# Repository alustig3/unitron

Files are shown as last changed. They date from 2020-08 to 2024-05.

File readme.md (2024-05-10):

# Unitron

<a href="https://certification.oshwa.org/us002571.html">

</a>

Unitron is a kitchen tool for working with important cooking units -- time, space, and mass -- using tactually-pleasing switches, knobs, and buttons, non-intrusive beeps, and exciting lights.

Unitron allows you to convert between common volume units (cups, ounces, tablespoons, teaspoons and milliliters). It can also convert from volume to mass (and vice-versa), taking into account the density of common cooking ingredients. This makes measuring ingredients for volume-based recipes with a kitchen scale a breeze. It also functions as a handy countdown timer!

Watch the demo video [here](https://vimeo.com/719658219).

Unitron was developed by Andy Lustig.

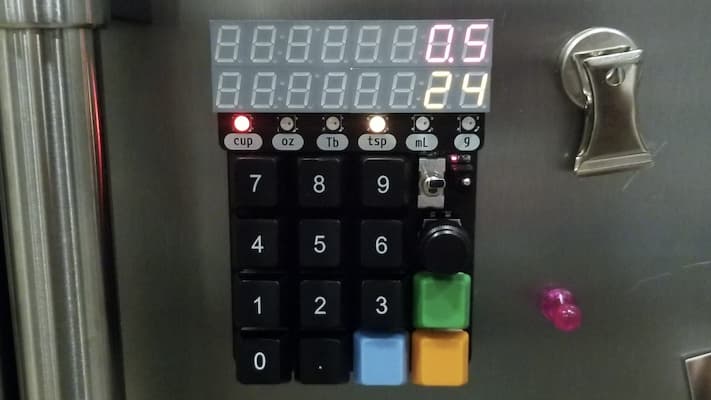
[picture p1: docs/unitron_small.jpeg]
unitron


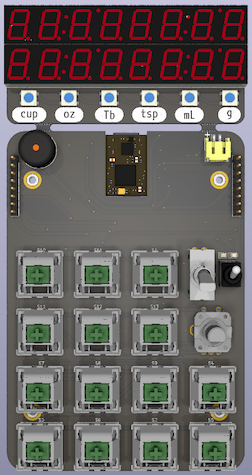
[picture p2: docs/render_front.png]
front render

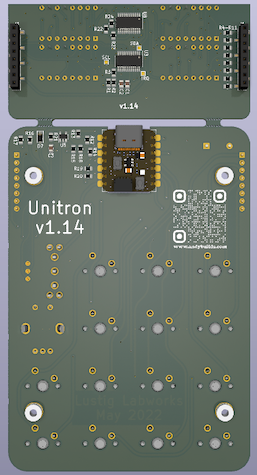
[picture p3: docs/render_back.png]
back render

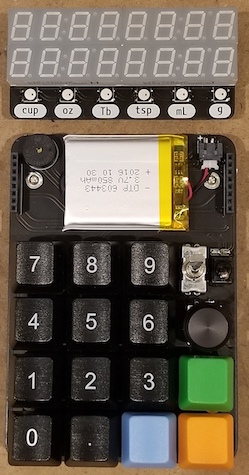
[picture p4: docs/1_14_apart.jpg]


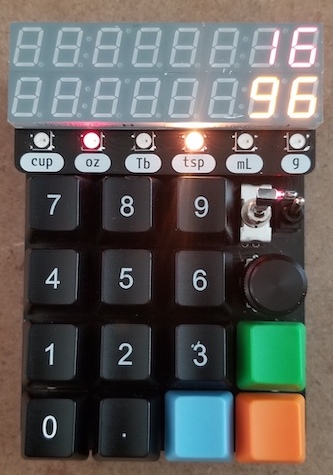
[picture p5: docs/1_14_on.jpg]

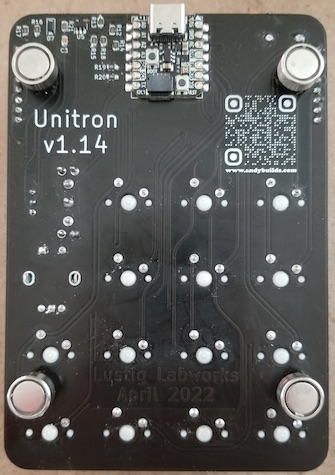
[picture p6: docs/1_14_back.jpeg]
back real


## Build Guide

### BOM

| Qty | Reference | Description | Value/MPN |
| --- | --- | --- | --- |
| 1 | BT2 | Battery Connector | [2468](https://www.digikey.com/product-detail/en/keystone-electronics/2466/36-2466-ND/303815) |
| 1 | C1 | 0805 Capacitor | 1µF |
| 1 | C2 | 0805 Capacitor | 100nF |
| 1 | C3 | 0805 Capacitor | 10µF |
| 6 | D1-6 | Addressable RGB LED | [WS2812B](https://cdn-shop.adafruit.com/datasheets/WS2812B.pdf) |
| 1 | D7 | Diode | [SM5817PL-TP](https://www.digikey.com/en/products/detail/micro-commercial-co/SM5817PL-TP/1793251) |
| 2 | D8, D9 | 0805 Indicator LED | Red and Yellow |
| 4 | H1-4 | Threaded Standoff | [4207](https://www.adafruit.com/product/4207) |
| 2 | J1, J3 | 1x8 male header | [TSM-108-01-T-SV](https://www.digikey.com/en/products/detail/samtec-inc/TSM-108-01-T-SV/6679033) |
| 2 | J2, J4 | 1x8 female header | [SSW-108-01-T-S](https://www.digikey.com/en/products/detail/samtec-inc/SSW-108-01-T-S/1112297) |
| 1 | LS1 | Buzzer | [PK-11N40PQ](https://www.digikey.com/en/products/detail/mallory-sonalert-products-inc/PK-11N40PQ/4996072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) |
| 21  | R1-18, R22-24 | 0805 Resistor | 10KΩ |
| 3 | R19, R20, R21 | 0805 Resistor | 2KΩ |
| 14  | S1-14 | Mechanical Key Switch | [Gateron green](https://www.amazon.com/Gateron-KS-9-Mechanical-Type-Switch/dp/B07X3TH4DS?th=1) |
| 1 | SW1 | Small Toggle | [B12AP](https://www.digikey.com/en/products/detail/nkk-switches/B12AP/379099) |
| 1 | SW2 | Big Toggle | [M2012EA2W13](https://www.digikey.com/en/products/detail/nkk-switches/M2012EA2W13/4509655) |
| 1 | SW3 | Rotary Encoder | [PEC11R-4215F-S0024](https://www.digikey.com/en/products/detail/bourns-inc/PEC11R-4215F-S0024/4499665) |
| 2 | U1, U2 | Yellow 4-Digit Display | [LTC-4727JS](https://www.digikey.com/products/en?keywords=LTC-4727JS) |
| 2 | U6, U7 | Red 4-Digit Display | [LTC-4727JR](https://www.digikey.com/products/en?keywords=160-1551-5-nd) |
| 2 | U3, U8 | 7-Segment Display Driver | [AS1115-BSST](https://www.digikey.com/products/en?keywords=AS1115-BSSTCT-ND) |
| 1 | U4 | QT Py RP2040 | [4900](https://www.adafruit.com/product/4900) |
| 1 | U5 | Battery Charging IC | [MCP73831](https://www.digikey.com/en/products/detail/microchip-technology/MCP73831T-2ATI-OT/964303) |

<div style="">
  <a href="https://alustig3.github.io/unitron/ibom.html">
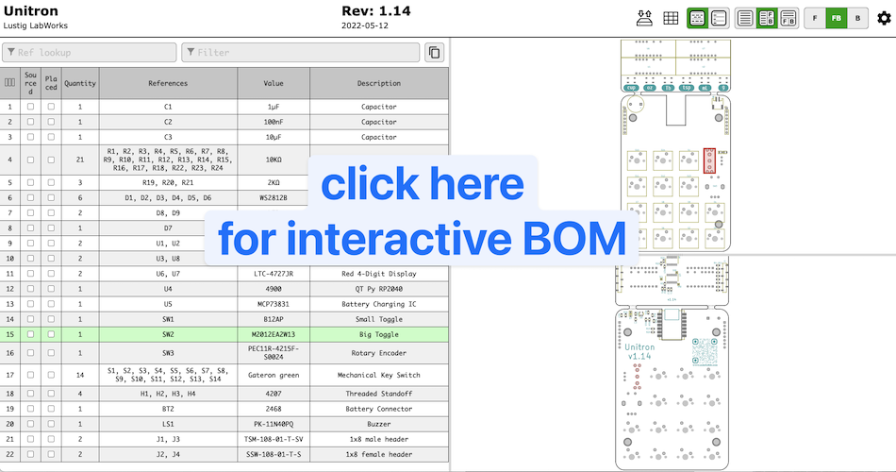
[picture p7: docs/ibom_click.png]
  
  </a>
</div>

### Additional Components
- A rechargeable 3.7V lithium polymer (LiPo) [battery](https://www.adafruit.com/product/1578)
- Threaded mounting [magnets](https://www.kjmagnetics.com/proddetail.asp?prod=MM-C-10)
- A satisfyingly knurled [metal knob](https://www.digikey.com/en/products/detail/kilo-international/OEDNI-63-4-7/5970335).
- Keycaps from WASD keycaps:
  - [number pad keycap set](https://www.wasdkeyboards.com/17-key-cherry-mx-number-pad-keycap-set.html) for the numbers (black, large font)
  - The number pad set comes with a 1x2 "0" keycap, but we want a [custom 1x1 "0" keycap](https://www.wasdkeyboards.com/custom-text-cherry-mx-keycaps.html) (R1 1x1, 26 font, center-center alignment)
  - [R1 1x1 keycaps](https://www.wasdkeyboards.com/row-1-size-1x1-cherry-mx-keycap.html) (sky blue, green, and orange)
- [Relegendable keycaps](https://www.adafruit.com/product/5039) are a good less expensive alternative.

## User Guide

### Component Diagram
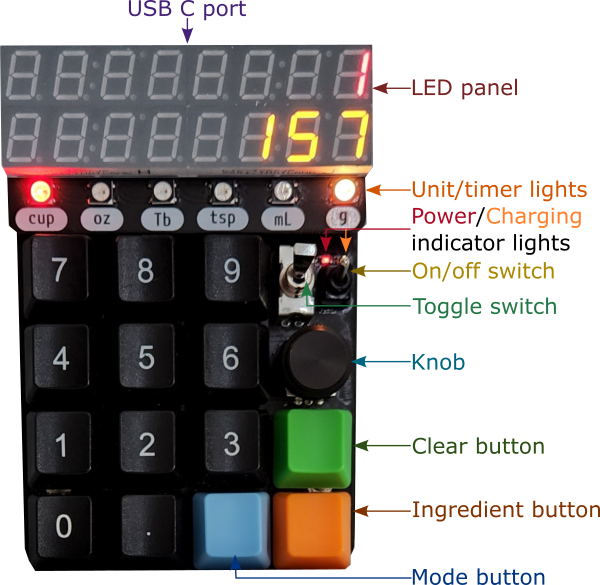
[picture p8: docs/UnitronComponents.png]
Unitron component diagram

### Turning it on!

The first step to using your Unitron is to turn it on with the smaller, right-most [On/Off switch](#diagram). When Unitron is on, the [LED panel](#diagram) and the red [Power indicator light](#diagram) will be lit up. Turn it off to save power.

### Switching Modes

Unitron has a [countdown timer mode](#timer) and [converter mode](#convert).
To **switch to modes**, click the [blue Mode button](#diagram).
Unitron will startup in the `start_mode` specified in your `settings.py` file (see [Modifying Unitron functionality](#modify)).
If the [blue Mode button](#diagram) is pressed down when turning on Unitron, it will startup in the opposite mode. 

### Countdown timer mode
To **set the timer**, use the number keys. To specify minutes and seconds, you can use the decimal key, e.g. 20.30 corresponds to 20 minutes and 30 seconds, while 20 corresponds to 20 seconds.

To **start** the timer, flip the [Toggle switch](#diagram). To **pause** the timer, flip the [Toggle switch](#diagram) again. The top, red row of the LED panel shows the time remaining, and the bottom orange row shows the original time requested.

To **clear** the timer, pause the timer (if necessary), then push the green [Clear button](#diagram).

As the timer counts down to 0, a bar of [Timer lights](#diagram) will progressively light up. When the timer reaches 0, it will beep three times.

### Converter mode
Unitron converts **from blinking to solid units** in the [Unit light](#diagram) row.

You can **enter the amount** of the **blinking "from"** units with the number keys. This will be shown in the [LED panel](#diagram). The corresponding amount in the **solid "to"** units will be shown in the other row of the [LED panel](#diagram).

You can **change units** using the [Knob](#diagram). Turning the knob changes the **blinking "from" units**. Turning the knob while holding it down changes the **solid "to" units**.

You can **swap** the "from" and "to" units with the [Toggle switch](#diagram).  If you find it difficult to hold down the Knob while turning it, you can use the Toggle switch to swap, turn the knob, then flip the Toggle switch back.

Conversions between volume and mass require knowing the density of the ingredient. You can **specify cooking ingredients** by holding down the orange [Ingredient button](#diagram) while turning the [Knob](#diagram). Note that the ingredient button only functions when the two units selected are mass and volume -- ingredient type does not matter when converting from mass to mass or volume to volume.

### Charging

Unitron is rechargeable. To charge it, plug a USB C cable into the [USB port](#diagram) at the top. The yellow charging indicator will be on while charging and will turn off when the battery is full.

### Placement

The back of Unitron has four strong magnets. It is meant to be placed on a metallic refrigerator.

###  Modifying Unitron functionality

Unitron uses [CircuitPython](https://learn.adafruit.com/welcome-to-circuitpython). 
You can modify the code it is running by connecting it to your computer via the [USB C port](#diagram) and mounting it as a disk drive.
Basic settings can be adjusted by editing the `settings.py` file.

**Change the mode that Unitron starts up in when turned on** by editing `start_mode`.

**Adjust the number of beeps** for when the timer expires by editing `beep_num`.

To **add new ingredients** to Unitron, modify `ingredients`. Specify the density in grams per teaspoon. You can try to measure these densities yourself, or you can trust the internet. Here's one [site](https://www.howmany.wiki/vw/) with information.

Make sure to **eject** Unitron before disconnecting.

### Updating 
#### CircuitPython
Connect Unitron to a computer via the [USB C port](#diagram).
To enter bootloader mode, hold down the `BOOT` button, and while continuing to hold it, press and release the `RST` button. Continue to hold the boot select button until the bootloader drive appears on your computer as `RPI-RP2`.
Download `adafruit-circuitpython-adafruit_qtpy_rp2040-en_US-9.0.4.uf2` file from the [release page](https://github.com/alustig3/unitron/releases) and drag it onto the bootloader drive. The `RPI-RP2` drive will disappear, and a new drive called `CIRCUITPY` will appear.

If you have trouble, take a look at the official CirtcuitPython installation instructions [here](https://learn.adafruit.com/welcome-to-circuitpython/installing-circuitpython).

#### Unitron Software
Connect Unitron to a computer via the [USB C port](#diagram).
It should appear as `CIRCUITPY`.
Download the latest software [release](https://github.com/alustig3/unitron/releases).
Unzip the download and copy the files onto the `CIRCUITPY` drive.

## License
[CERN Open Hardware Licence Version 2 - Permissive](https://github.com/alustig3/unitron/blob/main/LICENSE.txt)

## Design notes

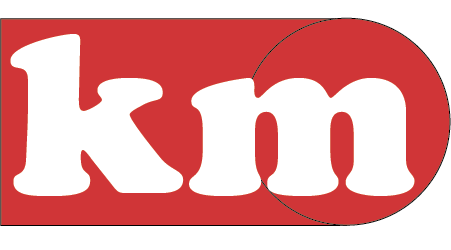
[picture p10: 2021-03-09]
pcb/labels/kilometer.png

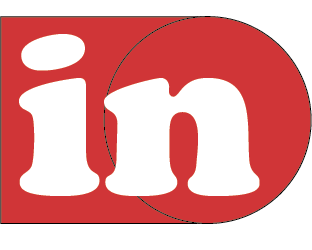
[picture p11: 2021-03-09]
pcb/labels/inches.png

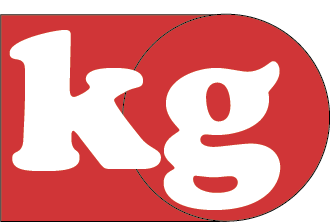
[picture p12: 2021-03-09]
pcb/labels/kilogram.png

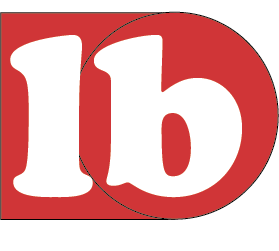
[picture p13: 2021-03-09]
pcb/labels/pounds.png

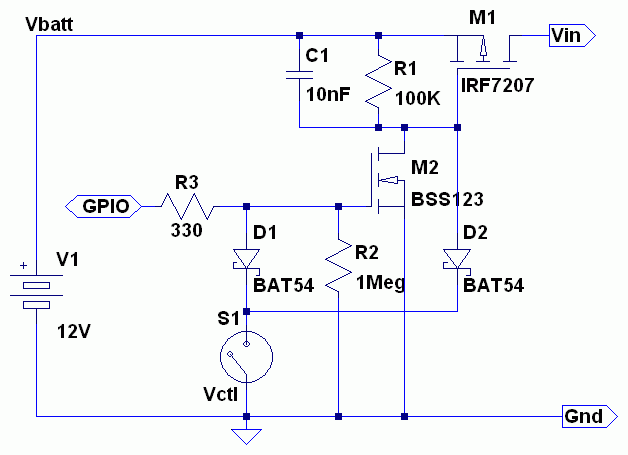
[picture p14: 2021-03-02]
pcb/datasheets/ArduSoftPwr.gif

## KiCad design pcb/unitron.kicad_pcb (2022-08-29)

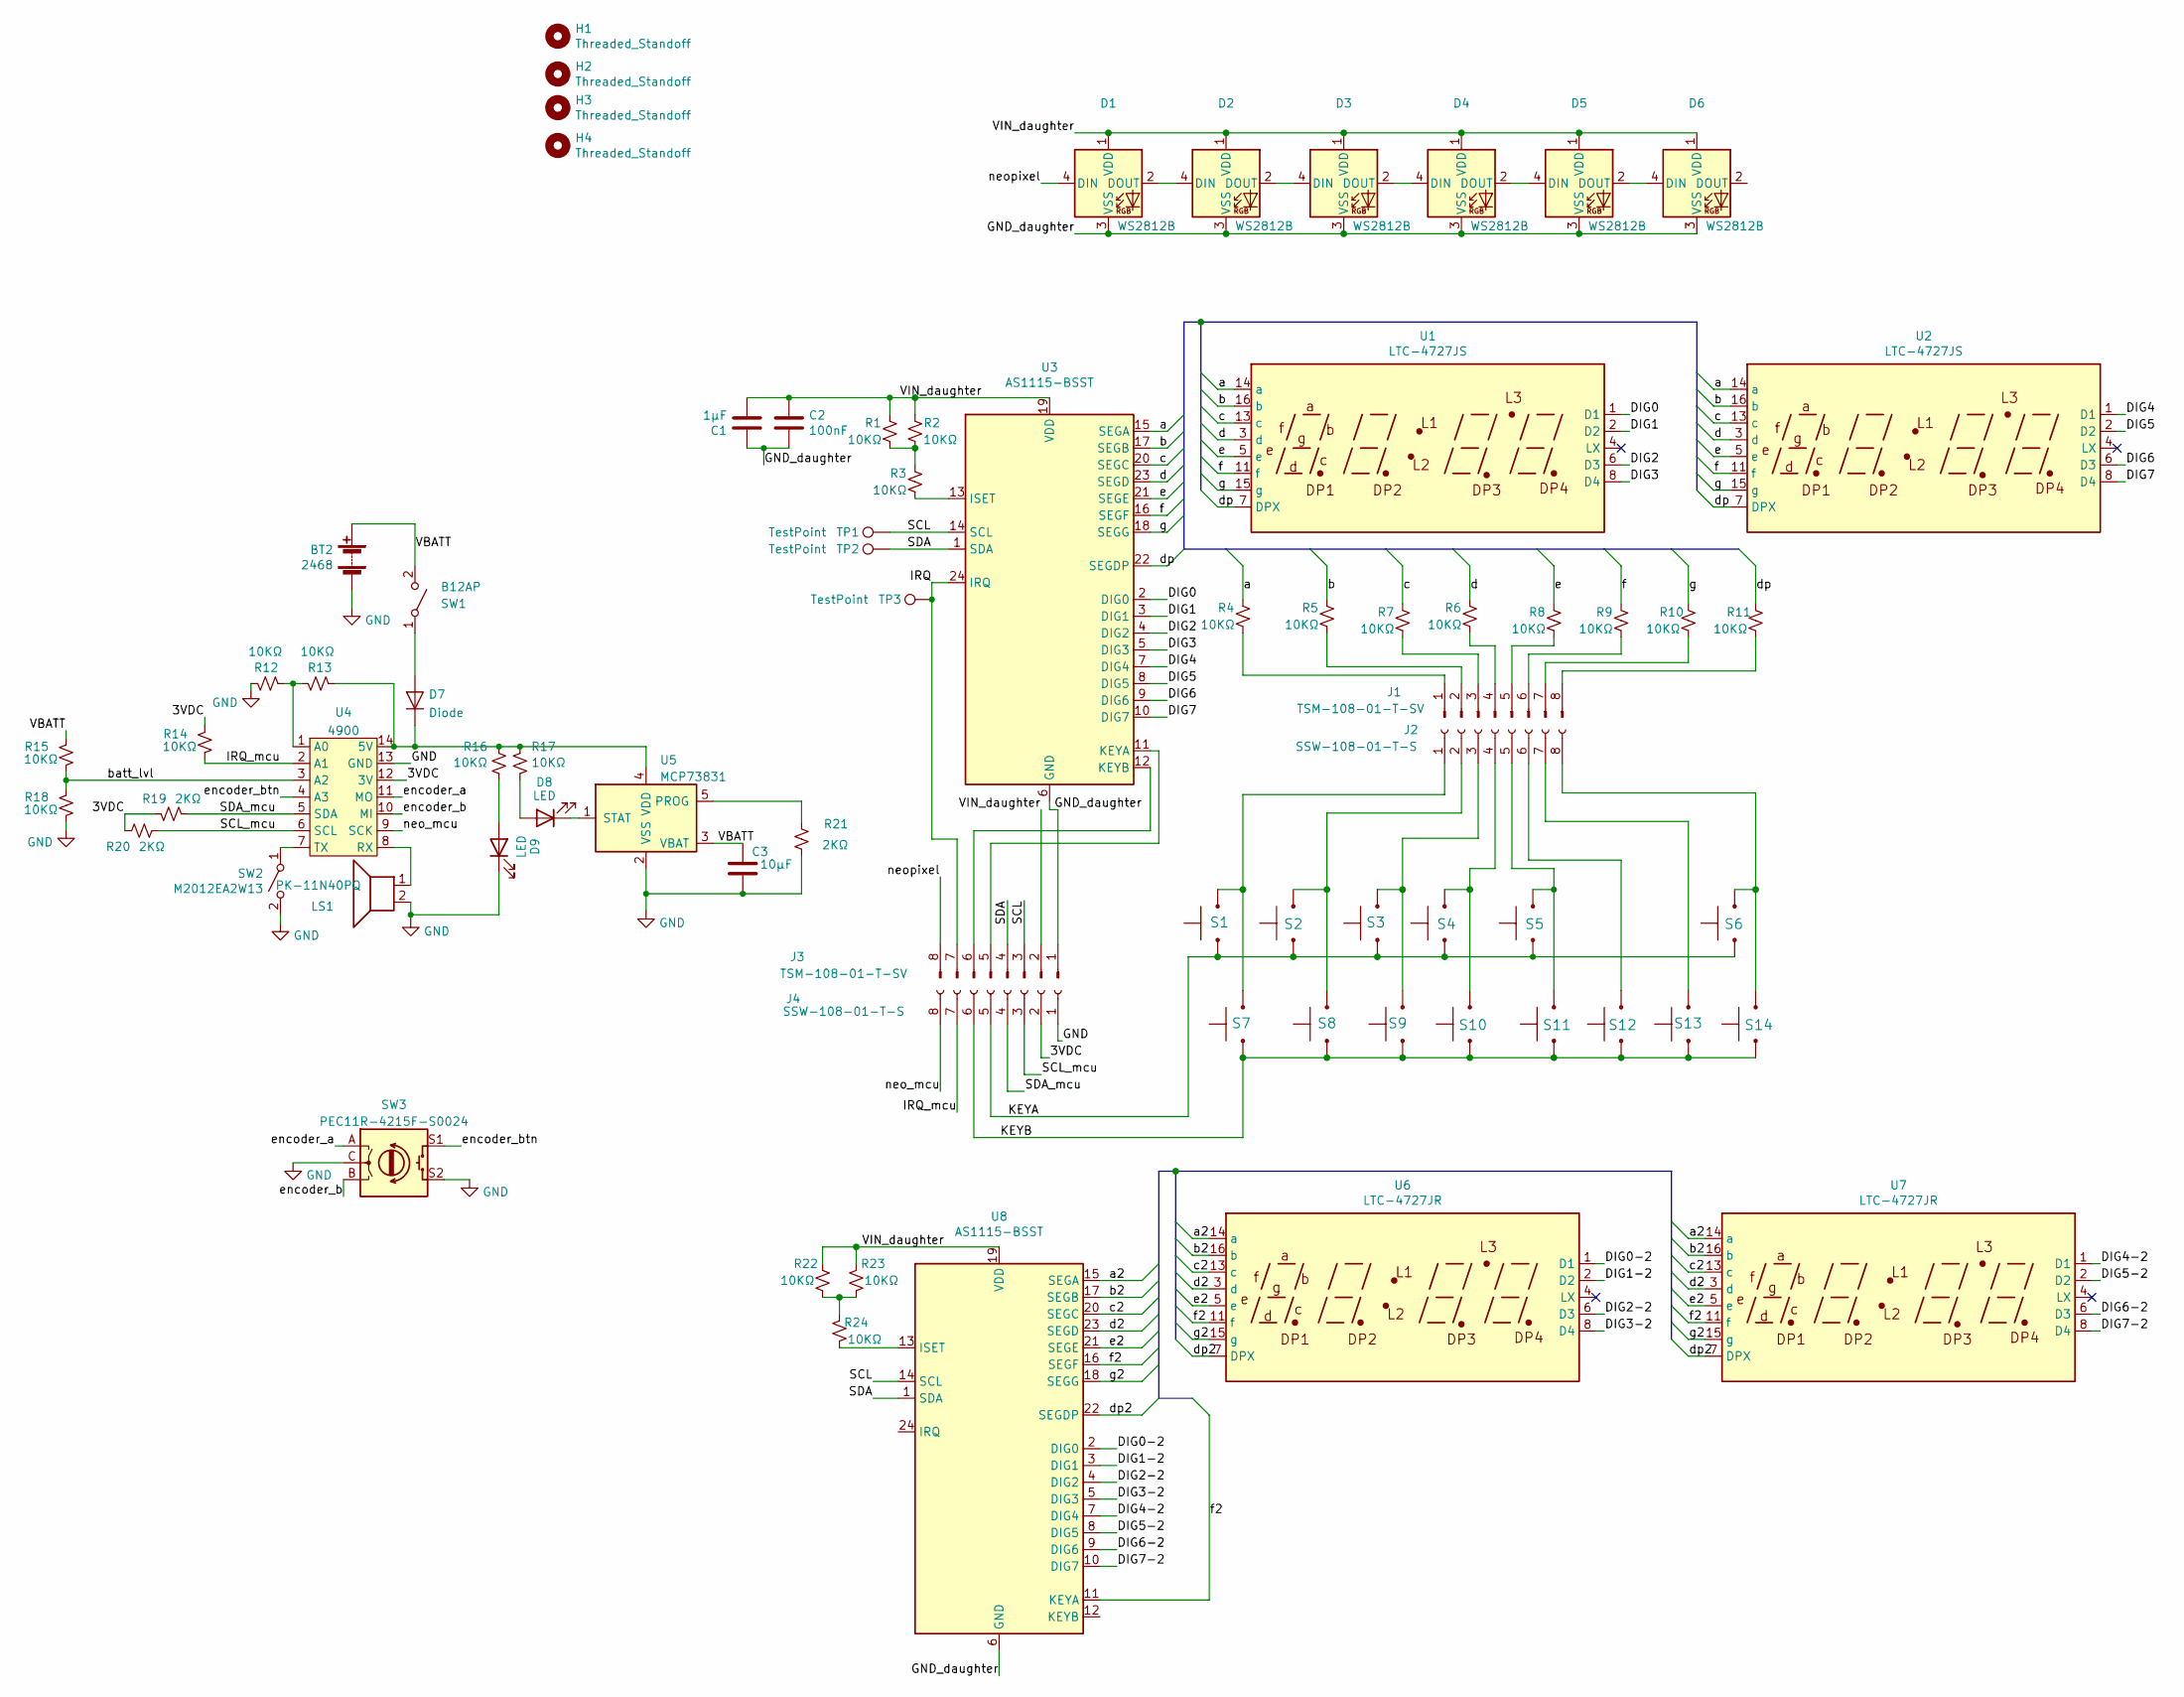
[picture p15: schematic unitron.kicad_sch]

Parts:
BT2: 2468; JST_PH_S2B-PH-SM4-TB_1x02-1MP_P2.00mm_Horizontal
C1: 1µF; C_0805_2012Metric
C2: 100nF; C_0805_2012Metric
C3: 10µF; C_0805_2012Metric
D1, D2, D3, D4, D5, D6: WS2812B; LED_WS2812B_PLCC4_5.0x5.0mm_P3.2mm
D7: Diode; D_SOD-123F
D8, D9: LED; LED_0805_2012Metric
H1, H2, H3, H4: Threaded_Standoff; standoff_nut
J1, J3: TSM-108-01-T-SV; PinSocket_1x08_P2.54mm_Vertical_SMD_Pin1Right
J2, J4: SSW-108-01-T-S; PinHeader_1x08_P2.54mm_Vertical
LS1: PK-11N40PQ; Buzzer_12x9.5RM7.6
R1, R2, R3, R4, R5, R6, R7, R8, R9, R10, R11, R12, R13, R14, R15, R16, R17, R18, R22, R23, R24: 10KΩ; R_0805_2012Metric
R19, R20, R21: 2KΩ; R_0805_2012Metric
S1, S2, S3, S4, S5, S6, S7, S8, S9, S10, S11, S12, S13, S14: Gateron green; SW_Cherry_MX_1.00u_PCB
SW1: B12AP; switch_toggle
SW2: M2012EA2W13; switch_nkk_reinforced_pc_pin
SW3: PEC11R-4215F-S0024; encoder_PEC11R
TP1, TP2, TP3: TestPoint; TestPoint_Pad_1.0x1.0mm
U1, U2: LTC-4727JS; LTC-4727
U3, U8: AS1115-BSST; QSOP-24_3.9x8.7mm_P0.635mm
U4: 4900; QT_Py
U5: MCP73831; SOT-23-5
U6, U7: LTC-4727JR; LTC-4727

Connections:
/3VDC: J4.2, R14.1, R19.2, R20.2, U4.12 (3V)
/DIG0: U1.1 (D1), U3.2 (DIG0)
/DIG0-2: U6.1 (D1), U8.2 (DIG0)
/DIG1: U1.2 (D2), U3.3 (DIG1)
/DIG1-2: U6.2 (D2), U8.3 (DIG1)
/DIG2: U1.6 (D3), U3.4 (DIG2)
/DIG2-2: U6.6 (D3), U8.4 (DIG2)
/DIG3: U1.8 (D4), U3.5 (DIG3)
/DIG3-2: U6.8 (D4), U8.5 (DIG3)
/DIG4: U2.1 (D1), U3.7 (DIG4)
/DIG4-2: U7.1 (D1), U8.7 (DIG4)
/DIG5: U2.2 (D2), U3.8 (DIG5)
/DIG5-2: U7.2 (D2), U8.8 (DIG5)
/DIG6: U2.6 (D3), U3.9 (DIG6)
/DIG6-2: U7.6 (D3), U8.9 (DIG6)
/DIG7: U2.8 (D4), U3.10 (DIG7)
/DIG7-2: U7.8 (D4), U8.10 (DIG7)
/GND_daughter: C1.1, C2.2, D1.3 (VSS), D2.3 (VSS), D3.3 (VSS), D4.3 (VSS), D5.3 (VSS), D6.3 (VSS), J3.1, U3.6 (GND), U8.6 (GND)
/IRQ: J3.7, TP3.1, U3.24 (IRQ)
/IRQ_mcu: J4.7, R14.2, U4.2 (A1)
/KEYA: J4.5, S1.1, S2.1, S3.1, S4.1, S5.1, S6.1
/KEYB: J4.6, S7.1, S8.1, S9.1, S10.1, S11.1, S12.1, S13.1, S14.1
/SCL: J3.3, TP1.1, U3.14 (SCL), U8.14 (SCL)
/SCL_mcu: J4.3, R20.1, U4.6 (SCL)
/SDA: J3.4, TP2.1, U3.1 (SDA), U8.1 (SDA)
/SDA_mcu: J4.4, R19.1, U4.5 (SDA)
/VBATT: BT2.1 (+), C3.1, R15.1, SW1.2 (B), U5.3 (VBAT)
/VIN_daughter: C1.2, C2.1, D1.1 (VDD), D2.1 (VDD), D3.1 (VDD), D4.1 (VDD), D5.1 (VDD), D6.1 (VDD), J3.2, R1.2, R2.2, R22.2, R23.2, U3.19 (VDD), U8.19 (VDD)
/a: R4.2, U1.14 (a), U2.14 (a), U3.15 (SEGA)
/a2: U6.14 (a), U7.14 (a), U8.15 (SEGA)
/b: R5.2, U1.16 (b), U2.16 (b), U3.17 (SEGB)
/b2: U6.16 (b), U7.16 (b), U8.17 (SEGB)
/batt_lvl: R15.2, R18.1, U4.3 (A2)
/c: R7.2, U1.13 (c), U2.13 (c), U3.20 (SEGC)
/c2: U6.13 (c), U7.13 (c), U8.20 (SEGC)
/d: R6.2, U1.3 (d), U2.3 (d), U3.23 (SEGD)
/d2: U6.3 (d), U7.3 (d), U8.23 (SEGD)
/dp: R11.2, U1.7 (DPX), U2.7 (DPX), U3.22 (SEGDP)
/dp2: U6.7 (DPX), U7.7 (DPX), U8.22 (SEGDP)
/e: R8.2, U1.5 (e), U2.5 (e), U3.21 (SEGE)
/e2: U6.5 (e), U7.5 (e), U8.21 (SEGE)
/encoder_a: SW3.A, U4.11 (MO)
/encoder_b: SW3.B, U4.10 (MI)
/encoder_btn: SW3.S1, U4.4 (A3)
/f: R9.2, U1.11 (f), U2.11 (f), U3.16 (SEGF)
/f2: U6.11 (f), U7.11 (f), U8.11 (KEYA), U8.16 (SEGF)
/g: R10.2, U1.15 (g), U2.15 (g), U3.18 (SEGG)
/g2: U6.15 (g), U7.15 (g), U8.18 (SEGG)
/neo_mcu: J4.8, U4.9 (SCK)
/neopixel: D1.4 (DIN), J3.8
GND: BT2.2 (-), C3.2, D9.1 (K), J4.1, LS1.2, R12.2, R18.2, R21.1, SW2.2 (B), SW3.C, SW3.S2, U4.13 (GND), U5.2 (VSS)
unnamed: D1.2 (DOUT), D2.4 (DIN)
unnamed: D2.2 (DOUT), D3.4 (DIN)
unnamed: D3.2 (DOUT), D4.4 (DIN)
unnamed: D4.2 (DOUT), D5.4 (DIN)
unnamed: D5.2 (DOUT), D6.4 (DIN)
unnamed: D7.1 (K), R13.1, R16.1, R17.1, U4.14 (5V), U5.4 (VDD)
unnamed: D7.2 (A), SW1.1 (A)
unnamed: D8.1 (K), U5.1 (STAT)
unnamed: D8.2 (A), R17.2
unnamed: D9.2 (A), R16.2
unnamed: J1.1, R4.1
unnamed: J1.2, R5.1
unnamed: J1.3, R7.1
unnamed: J1.4, R6.1
unnamed: J1.5, R8.1
unnamed: J1.6, R9.1
unnamed: J1.7, R10.1
unnamed: J1.8, R11.1
unnamed: J2.1, S1.2, S7.2
unnamed: J2.2, S2.2, S8.2
unnamed: J2.3, S3.2, S9.2
unnamed: J2.4, S4.2, S10.2
unnamed: J2.5, S5.2, S11.2
unnamed: J2.6, S12.2
unnamed: J2.7, S13.2
unnamed: J2.8, S6.2, S14.2
unnamed: J3.5, U3.11 (KEYA)
unnamed: J3.6, U3.12 (KEYB)
unnamed: LS1.1, U4.8 (RX)
unnamed: R1.1, R2.1, R3.2
unnamed: R3.1, U3.13 (ISET)
unnamed: R12.1, R13.2, U4.1 (A0)
unnamed: R21.2, U5.5 (PROG)
unnamed: R22.1, R23.1, R24.2
unnamed: R24.1, U8.13 (ISET)
unnamed: SW2.1 (A), U4.7 (TX)

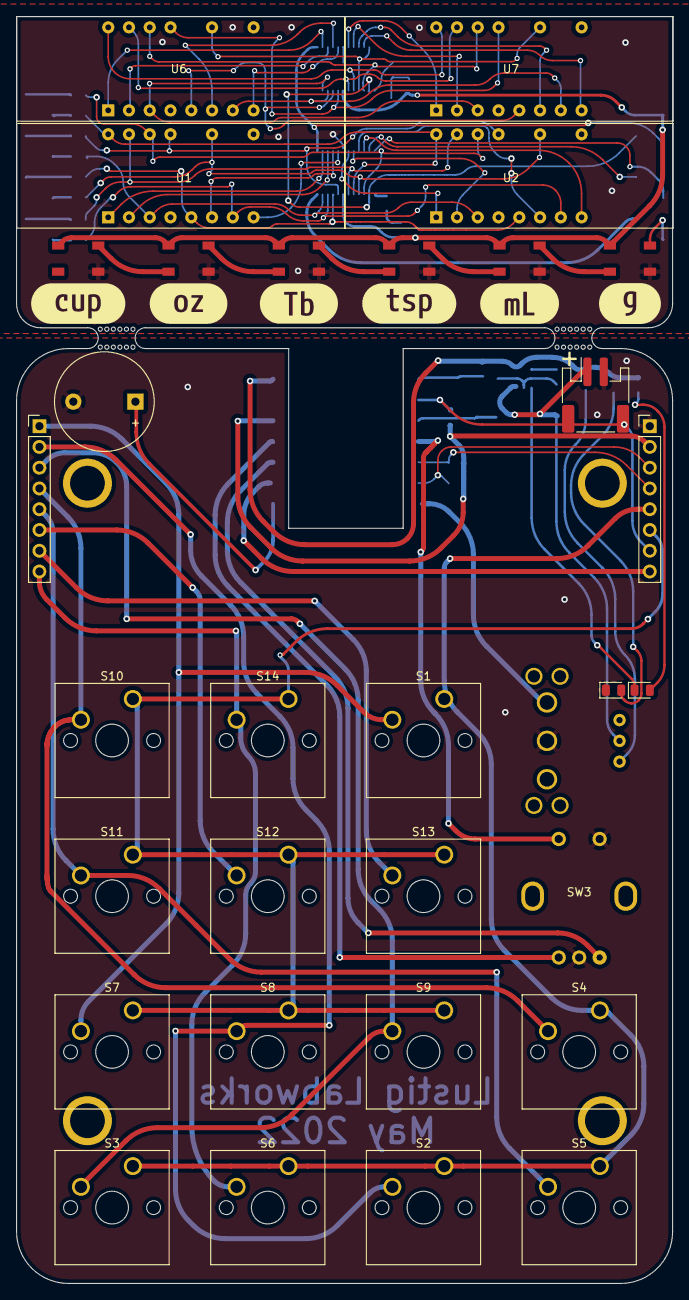
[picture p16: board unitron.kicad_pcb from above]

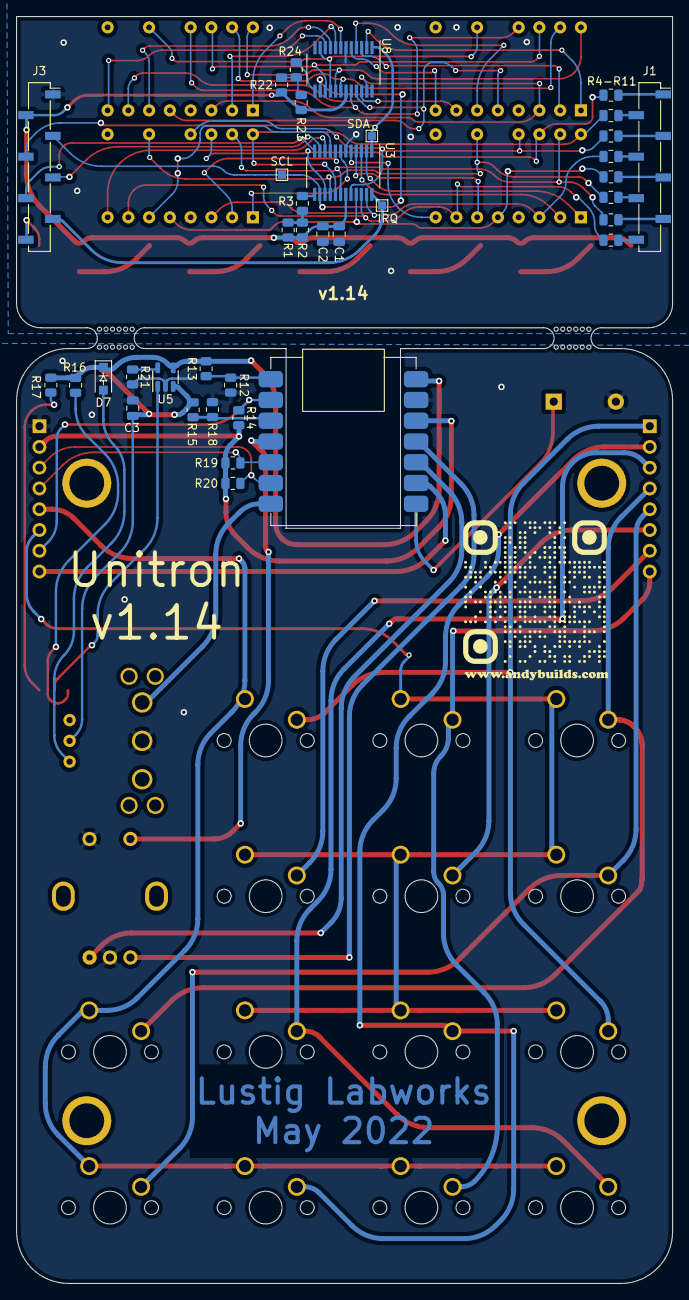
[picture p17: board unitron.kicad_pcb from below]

Board: 2 copper layers, 80.3 x 155.0 mm, 82 parts (37 on the bottom side), 87 nets.

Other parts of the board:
MB*: VAL**; mouse-bite-2.54mm-slot-long
MB*#2: VAL**; mouse-bite-2.54mm-slot-long
kibuzzard-6260D7DE: G***; kibuzzard-6260D7DE
kibuzzard-6260D82F: G***; kibuzzard-6260D82F
kibuzzard-6260D796: G***; kibuzzard-6260D796
kibuzzard-6260D857: G***; kibuzzard-6260D857
kibuzzard-6260D976: G***; kibuzzard-6260D976
kibuzzard-6260DA5E: G***; kibuzzard-6260DA5E

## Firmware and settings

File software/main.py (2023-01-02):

# https://learn.adafruit.com/keep-your-circuitpython-libraries-on-devices-up-to-date-with-circup/usage
import microcontroller
import asyncio
import time
from unitron import Physical, Interface, RED, YELLOW, BLACK, GREEN
from settings import beep_num


unitron = Physical()
start_opposite = unitron.btm_disp.read() == "mode_btn"
interface = Interface(unitron, start_opposite)


def timer_mode():
    interface.mode = "timer"
    interface.top = "0"
    interface.btm = ""
    unitron.top_disp.dim(False)
    unitron.btm_disp.dim(False)
    unitron.pixels.fill(0)
    unitron.pixels.show()
    interface.mode_switch = True
    unitron.top_disp.text(" tiMmer ")
    unitron.btm_disp.text("        ")
    time.sleep(0.75)


def converter_mode():
    interface.clear()
    interface.mode = "converter"
    unitron.top_disp.dim(False)
    unitron.btm_disp.dim(False)
    unitron.top_disp.text("Convert ")
    unitron.btm_disp.text("        ")
    time.sleep(0.75)
    interface.run_conversion()


async def check_inputs():
    unitron.top_disp.text("Unitron ")
    unitron.btm_disp.text("        ")
    time.sleep(0.75)

    if interface.mode == "timer":
        timer_mode()
    elif interface.mode == "converter":
        converter_mode()
    while True:
        if interface.mode == "converter":
            if (unitron.keypress.value) == False:
                key = unitron.btm_disp.read()
                if key:
                    if key == "clear_btn":
                        if interface.toggle_up:
                            unitron.top_disp.clear(interface.top)
                        else:
                            unitron.btm_disp.clear(interface.top)
                        time.sleep(0.2)
                        interface.clear()
                    elif key == "mode_btn":
                        timer_mode()
                    elif key == ".":
                        if interface.digits_after_decimal < 0 and len(interface.top) < 3:
                            interface.digits_after_decimal += 1
                            interface.top += key
                    elif key == "ingredient_btn":
                        if interface.top_index == 5 or interface.bottom_index == 5:
                            unitron.top_disp.text(interface.ingredient.title, "")
                            unitron.btm_disp.text(interface.ingredient.title2, "")
                            while unitron.btm_disp.read() == "ingredient_btn":
                                unitron.top_disp.dim(False)
                                unitron.btm_disp.dim(False)
                                turned = unitron.knob.read()
                                if turned:
                                    interface.change_ingredient(turned)
                                    unitron.top_disp.text(interface.ingredient.title, right_justify=False)
                                    unitron.btm_disp.text(interface.ingredient.title2, right_justify=False)
                                interface.run_conversion()
                            # save the ingredient index to non-volatile memory so Unitron will startup using the last used ingredient
                            microcontroller.nvm[0] = interface.ingredient_index

                    elif key == "unknown":  # unrecognized input. maybe multiple keys are being held down
                        interface.skip_rebound = True
                    elif key == "release":
                        pass
                    else:
                        if interface.skip_rebound:
                            interface.skip_rebound = False
                        else:
                            if interface.top == "0" and key != ".":
                                # replace  0 with new number
                                interface.top = str(key)
                            else:
                                if interface.digits_after_decimal < 2:
                                    if interface.digits_after_decimal > -1:
                                        if float(interface.top) < 10000:
                                            interface.digits_after_decimal += 1
                                            interface.top += str(key)
                                    elif 10 * float(interface.top) < 10000:
                                        interface.top += str(key)
                    if interface.mode == "converter":
                        interface.run_conversion()

            # check for knob rotation
            turned = unitron.knob.read()
            if turned:
                # rotating changes blinking input unit
                if unitron.knob.btn.value == 1:
                    interface.change_unit(interface.toggle_up, turned)

                # rotating while pressing changes output unit
                else:
                    interface.change_unit(not interface.toggle_up, turned)
                interface.run_conversion()

            if interface.toggle_up != unitron.toggle.value:
                interface.toggle_up = unitron.toggle.value
                interface.run_conversion()

        elif interface.mode == "timer":
            if (unitron.keypress.value) == False:
                # p = unitron.battery_lvl.value / 65535 * 3.3 * 2
                # interface.top = p
                key = unitron.btm_disp.read()
                if key and interface.is_ticking == False:
                    if key == "clear_btn":
                        unitron.top_disp.clear(interface.top)
                        time.sleep(0.2)
                        interface.clear()
                    elif key == "mode_btn":
                        converter_mode()
                    elif key == ".":
                        if interface.dot_added < 3 and interface.top[-1] != ".":
                            interface.dot_added += 1
                            interface.top += str(key)
                    elif key == "ingredient_btn":
                        pass
                    elif key == "unknown":  # unrecognized input. maybe multiple keys are being held down
                        interface.skip_rebound = True
                    elif key == "release":
                        pass
                    else:
                        if interface.skip_rebound:
                            interface.skip_rebound = False
                        else:
                            if interface.top == "0" and key != ".":
                                interface.top = str(key)
                            else:
                                interface.top += str(key)
            if interface.toggle_up != unitron.toggle.value:
                interface.toggle_up = unitron.toggle.value
                seconds_on_clock = interface.clock_str_to_seconds(interface.top)
                if seconds_on_clock > 0:
                    interface.is_ticking = not interface.is_ticking
                    if interface.is_ticking:
                        if interface.clock_percentage != 0:
                            pass
                        else:
                            interface.top = interface.seconds_to_clock_str(seconds_on_clock)
                            interface.btm = interface.top
                            interface.clock_percentage = 0
                            unitron.pixels.fill(0)
        await asyncio.sleep(0)


async def show():
    while True:
        if interface.mode == "converter":
            if interface.toggle_up:
                unitron.top_disp.text((interface.top))
                unitron.btm_disp.text((interface.btm))
            else:
                unitron.top_disp.text((interface.btm))
                unitron.btm_disp.text((interface.top))
            await asyncio.sleep(0)
        else:
            unitron.top_disp.time(interface.top)
            unitron.btm_disp.time(interface.btm)
            await asyncio.sleep(0)


async def blink(interval):
    num_pixels = 6
    while True:
        if interface.mode == "converter":
            if interface.toggle_up:
                unitron.top_disp.dim(True)
                interface.indicator("top", BLACK)
                await asyncio.sleep(interval)

                unitron.top_disp.dim(False)
                if interface.mode == "converter":
                    interface.indicator("top", RED)
                    interface.indicator("bottom", YELLOW)
            else:
                unitron.btm_disp.dim(True)
                interface.indicator("bottom", BLACK)
                await asyncio.sleep(interval)

                unitron.btm_disp.dim(False)
                if interface.mode == "converter":
                    interface.indicator("top", RED)
                    interface.indicator("bottom", YELLOW)
        elif interface.mode_switch:
            unitron.pixels.fill(0)
            unitron.pixels.show()
            interface.mode_switch = False

        await asyncio.sleep(interval)


async def tick():
    while True:
        if interface.mode == "timer" and interface.is_ticking:
            total = interface.clock_str_to_seconds(interface.top)
            if total <= 0:
                for _ in range(beep_num):
                    for _ in range(4):
                        if interface.is_ticking:
                            unitron.speaker.value = True
                            unitron.pixels.fill(GREEN)
                            await asyncio.sleep(beep_length := 0.05)
                            unitron.speaker.value = False
                            unitron.pixels.fill(BLACK)
                            await asyncio.sleep(beep_length)
                    if interface.is_ticking:
                        await asyncio.sleep(5 * beep_length)
                interface.is_ticking = False
                interface.top = interface.btm
                await asyncio.sleep(0)
            else:
                await asyncio.sleep(1)
                if interface.is_ticking:
                    total -= 1
                    interface.clock_percentage = 1 - total / interface.clock_str_to_seconds(interface.btm)
                    progress = interface.clock_percentage * 1530
                    interface.top = interface.seconds_to_clock_str(total)
                    if progress >= 1275:
                        unitron.pixels[5] = (0, 255, 0)
                        unitron.pixels[4] = (0, 255, 0)
                        unitron.pixels[3] = (0, 255, 0)
                        unitron.pixels[2] = (0, 255, 0)
                        unitron.pixels[1] = (0, 255, 0)
                        unitron.pixels[0] = (0, progress % 255, 0)
                    elif progress >= 1020:
                        unitron.pixels[5] = (0, 255, 0)
                        unitron.pixels[4] = (0, 255, 0)
                        unitron.pixels[3] = (0, 255, 0)
                        unitron.pixels[2] = (0, 255, 0)
                        unitron.pixels[1] = (0, progress % 255, 0)
                    elif progress >= 765:
                        unitron.pixels[5] = (0, 255, 0)
                        unitron.pixels[4] = (0, 255, 0)
                        unitron.pixels[3] = (0, 255, 0)
                        unitron.pixels[2] = (0, progress % 255, 0)
                    elif progress >= 510:
                        unitron.pixels[5] = (0, 255, 0)
                        unitron.pixels[4] = (0, 255, 0)
                        unitron.pixels[3] = (0, progress % 255, 0)
                    elif progress >= 255:
                        unitron.pixels[5] = (0, 255, 0)
                        unitron.pixels[4] = (0, progress % 255, 0)
                    else:
                        unitron.pixels[5] = (0, progress % 255, 0)

                    unitron.pixels.show()
        else:
            await asyncio.sleep(0)


async def main():
    inputs_task = asyncio.create_task(check_inputs())
    blink_task = asyncio.create_task(blink(0.20))
    show_task = asyncio.create_task(show())
    tick_task = asyncio.create_task(tick())
    await asyncio.gather(inputs_task, blink_task, show_task, tick_task)


asyncio.run(main())

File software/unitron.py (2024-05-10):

import microcontroller
import time
import alarm
import busio
import rotaryio
import board
import as1115 as driver
import neopixel
import math
import re
from adafruit_bus_device.i2c_device import I2CDevice
from digitalio import DigitalInOut, Direction, Pull
from analogio import AnalogIn
from conversions import conversions
from settings import start_mode, ingredients

RED = (128, 0, 0)
GREEN = (0, 128, 0)
YELLOW = (128, 54, 0)
BLACK = (0, 0, 0)

regex = re.compile("\.")


class Knob:
    def __init__(self, enc_pin_1, enc_pin_2, btn_pin):
        self.encoder = rotaryio.IncrementalEncoder(enc_pin_1, enc_pin_2)
        self.last_pos = 0
        self.btn = DigitalInOut(btn_pin)
        self.btn.switch_to_input(Pull.UP)

    def read(self):
        change = self.encoder.position - self.last_pos
        if change > 0:
            change = 1
        elif change < 0:
            change = -1
        self.last_pos += change
        time.sleep(0.01)
        return change


class Physical:
    def __init__(self):
        numDigits = 8
        i2cbus = busio.I2C(board.SCL, board.SDA, frequency=1_000_000)
        try:
            i2c_device = I2CDevice(i2cbus, 0)
            with i2c_device as bus_device:
                bus_device.write(bytes([driver.SHUTDOWN, 0x01]))
                bus_device.write(bytes([driver.DECODE, 0x00]))
                bus_device.write(bytes([driver.KEYSCAN, numDigits - 1]))
                bus_device.write(bytes([driver.INTENSITY, 10]))
                bus_device.write(bytes([0x2D, 0x01]))  # set self addressing mode
            time.sleep(0.12)
            print("fresh start up with address 0")
        except ValueError:
            print("already self-addressing")

        pixel_pin = board.SCK
        self.num_pixels = 6
        self.pixels = neopixel.NeoPixel(pixel_pin, self.num_pixels, brightness=0.1)
        self.pixels.fill(BLACK)
        self.pixels.show()

        self.top_disp = driver.SegmentDisplay(1, i2cbus)
        self.btm_disp = driver.SegmentDisplay(3, i2cbus)
        self.top_disp.wake()
        self.btm_disp.wake()

        self.knob = Knob(board.MOSI, board.MISO, board.A3)

        self.speaker = DigitalInOut(board.RX)
        self.speaker.direction = Direction.OUTPUT
        self.speaker.value = 0

        self.keypress = DigitalInOut(board.A1)
        self.keypress.switch_to_input(Pull.UP)

        self.toggle = DigitalInOut(board.TX)
        self.toggle.switch_to_input(Pull.UP)

        self.battery_lvl = AnalogIn(board.A2)

    def sleep(self):
        self.pwr_btn.deinit()
        pin_alarm = alarm.pin.PinAlarm(pin=board.TX, value=False, pull=True)
        self.top_disp.sleep()
        self.btm_disp.sleep()
        self.pixels.fill(0)

        # alarm.light_sleep_until_alarms(time_alarm)
        alarm.exit_and_deep_sleep_until_alarms(pin_alarm)

        self.pwr_btn = DigitalInOut(board.TX)
        self.pwr_btn.direction = Direction.INPUT
        self.pwr_btn.pull = Pull.UP
        self.top_disp.wake()
        self.btm_disp.wake()


class Interface:
    def __init__(self, unitron, start_opposite):
        self.toggle_up = True
        self.top = "0"
        self.btm = "0"

        self.ingredient_index = microcontroller.nvm[0]  # recall the last used ingredient from non-volatile memory
        try:
            self.ingredient = ingredients[self.ingredient_index]
        except IndexError:
            self.ingredient_index = 0
        self.ingredient = ingredients[self.ingredient_index]

        self.top_index = 0
        self.bottom_index = 5
        self.top_unit = conversions[self.top_index]
        self.bottom_unit = conversions[self.bottom_index]

        self.converter = conversions[0]
        if start_opposite:
            if start_mode == "converter":
                self.mode = "timer"
            else:
                self.mode = "converter"
        else:
            self.mode = start_mode
        self.digits_after_decimal = -1
        self.dot_added = 0

        self.unitron = unitron
        self.indicator("top", BLACK)
        self.indicator("bottom", BLACK)
        self.count = 0
        self.negative_input = False
        self.skip_rebound = False

        self.is_ticking = False
        self.clock_percentage = 0
        self.mode_switch = False

    def run_conversion(self):
        if self.toggle_up:
            self.btm = self.bottom_unit.from_tsp(self.top_unit.to_tsp(self.top))
            if len(self.btm) > 8:
                self.top = self.top[:-1]
                self.btm = self.bottom_unit.from_tsp(self.top_unit.to_tsp(self.top))
        else:
            self.btm = self.top_unit.from_tsp(self.bottom_unit.to_tsp(self.top))
            if len(self.btm) > 8:
                self.top = self.top[:-1]
                self.btm = self.top_unit.from_tsp(self.bottom_unit.to_tsp(self.top))

    def change_unit(self, toggle_is_up, direction):
        if toggle_is_up:
            self.indicator("top", BLACK)
            self.top_index += direction
            if self.top_index >= len(conversions) or self.top_index < 0:
                self.top_index -= len(conversions) * direction
                if self.top_index == self.bottom_index:
                    self.top_index += direction
            if self.top_index == self.bottom_index:
                self.top_index += direction
                if self.top_index >= len(conversions) or self.top_index < 0:
                    self.top_index -= len(conversions) * direction
            self.indicator("top", RED)
        else:
            self.indicator("bottom", BLACK)
            self.bottom_index += direction
            if self.bottom_index >= len(conversions) or self.bottom_index < 0:
                self.bottom_index -= len(conversions) * direction
                if self.top_index == self.bottom_index:
                    self.bottom_index += direction
            if self.top_index == self.bottom_index:
                self.bottom_index += direction
                if self.bottom_index >= len(conversions) or self.bottom_index < 0:
                    self.bottom_index -= len(conversions) * direction
            self.indicator("bottom", YELLOW)
        self.update_units()

    def indicator(self, location, color):
        if location == "top":
            location = self.top_index
        else:
            location = self.bottom_index
        self.unitron.pixels[self.unitron.num_pixels - 1 - location] = color

    def change_ingredient(self, direction):
        self.ingredient_index += direction
        if self.ingredient_index > len(ingredients) - 1:
            self.ingredient_index -= len(ingredients)
        elif self.ingredient_index < 0:
            self.ingredient_index += len(ingredients)
        self.ingredient = ingredients[self.ingredient_index]
        conversions[-1] = self.ingredient
        self.update_units()

    def update_units(self):
        self.top_unit = conversions[self.top_index]
        self.bottom_unit = conversions[self.bottom_index]
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

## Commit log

2020-05-08 first version of pcb. 32u4, toggle switch 1 row/8 digits display
    [imperializer-B_Cu.gbr, imperializer-B_Mask.gbr, imperializer-B_Paste.gbr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]
2020-06-06 keys, mode toggle switch, and 2 displays working
2020-06-06 increments only down downstroke. switch moves the number between left and right side.
2020-06-10 working with 2 drivers, 4 displays
2020-06-11 fixes 0 being inserted when keys are quickly pressed in succession.
2020-06-21 slower clock I2C clock speed make startup more reliable.
2020-08-02 pcb v1.1
    [imperializer-B_Cu.gbr, imperializer-B_Mask.gbr, imperializer-B_Paste.gbr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]
2020-09-15 pcb v1.2
    switched to bare SAMD21
    added USB-C connector
    added 4 conversion selection LEDs
    added on/off button with soft latch circuit
    rearranged toggles switch and battery holders
    [imperializer-B_Cu.gbr, imperializer-B_Mask.gbr, imperializer-B_Paste.gbr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]
2020-09-17 Kicad update
    updated to kicad 5.99 nightly. There is now a new file format
    [imperializer.kicad_pcb, imperializer.kicad_sch, imperializer.sch]
2020-10-18 v1.2 features added
    soft latch works. press to turn on, hold to turn off
    can cycle through conversion modes. corresponding indicator LEDs will light up
    can specify number of decimals and if number is negative.
    sends keypresses to computer as keyboard device
2020-10-19 Modified to work with esp32 feather
2020-10-26 pcb v1.3
    [bom.xlsx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]
2020-11-05 added clear and negative button functionality
2020-11-30 update pcb library
2021-02-02 pcb v1.4
    [bom.xlsx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]
2021-02-14 PCB v1.5
    [bom.xlsx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]
2021-02-24 working software
    - corresponding leds light up when units change
    - last used unit is saved and retrieved from EEPROM
2021-03-02 added mechanical files
    [stand.dxf]
2021-03-02 added gdb commands for blackmagic probe
2021-03-07 clear line animation
    lines sweep left then right on input when clear button is used
2021-03-09 pcb v1.6
    [unitron-B_Cu.gbr, unitron-B_Mask.gbr, unitron-B_Paste.gbr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]
2021-10-30 pcb v1.7
2021-11-21 unitron v 1.8
    changed to QT PY and added lipo battery charging circuit
    [unitron-B_Cu.gbr, unitron-B_Mask.gbr, unitron-B_Paste.gbr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]
2021-12-13 pcb v1.9
    [unitron-B_Cu.gbr, unitron-B_Mask.gbr, unitron-B_Paste.gbr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]
2022-01-10 v1.10
    shift as1115 label closer to pin 1
    remove "1" label from km neopixel
    make IRQ trace and via larger.
    change i2c pullups from 10k to 2k
    added diodes to keyscan traces so multiple buttons can simultaneously be pressed
    make cutout for different qt py
    [unitron.kicad_pcb, unitron.kicad_sch]
2022-03-19 v 1.11
    [unitron-B_Cu.gbr, unitron-B_Mask.gbr, unitron-B_Paste.gbr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]
2022-03-23 pcb v1.12
    [unitron-B_Cu.gbr, unitron-B_Mask.gbr, unitron-B_Paste.gbr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]
2022-04-25 pcb v1.13
    [unitron-B_Cu.gbr, unitron-B_Mask.gbr, unitron-B_Paste.gbr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]
2022-05-15 pcb v1.14
    [unitron-B_Cu.gbr, unitron-B_Mask.gbr, unitron-B_Paste.gbr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]
2022-05-21 starting to add timer
2022-05-22 basic timer working with progress bar
2022-06-04 clock interface working with timer
2022-06-04 toggling while tick will now pause the timer
2022-07-12 starts up in timer mode
    updated libraries as well
2022-08-29 clean up directory for sharing
    [stand.dxf, unitron.kicad_pcb, unitron.kicad_sch]
2022-08-29 condensed BOM values
2023-01-01 Unitron will startup opposite of its default mode if the mode button is pressed when Unitron is switched on
2023-01-02 fix crash that happened if ingredient button pressed while in countdown mode
    [main.py]
2023-01-02 changed countdown timer display text
2024-05-10 update libraries for CircuitPython 9
2024-05-10 fix out of index bug that occurs during very first startup
    [unitron.py]
